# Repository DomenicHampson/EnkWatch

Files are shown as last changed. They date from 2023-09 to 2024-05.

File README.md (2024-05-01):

# EnkWatch
<h6>Note: I am still in the process of writing the firmware and mechanical design</h6>
<h4>Custom designed e-ink smartwatch with 2 weeks of battery life! The watch uses a PIC MCU with a built in RTC module and attached to an external temperature and humidity
    sensor via SPI bus to display data to the user on a e-ink screen. The time/date and off-times are set, aswell as the sensors calibrated through USB 2.0 by the user through
    python scripts. The watch is enclosed is a 3D printed shell designed using solidworks.</h4>

<h4><u>Features</u></h4>
<ul>
  <li>2 Week Battery Life: Use low power components and efficient firmware to maximize battery life</li>
  <li>Power Switching and Protection: USB power can simulatenously charge the battery and power the watch. Battery overchage protection provided by a management IC and over
      discharge protection via mosfet controlled by the PIC.</li>
  <li>USB 2.0 Communication: User can ineract with the MCU through USB to set the time/date, calibrate the altitude sensor and determine at which times to power down their watch
      (for greater battery life).</li>
</ul>

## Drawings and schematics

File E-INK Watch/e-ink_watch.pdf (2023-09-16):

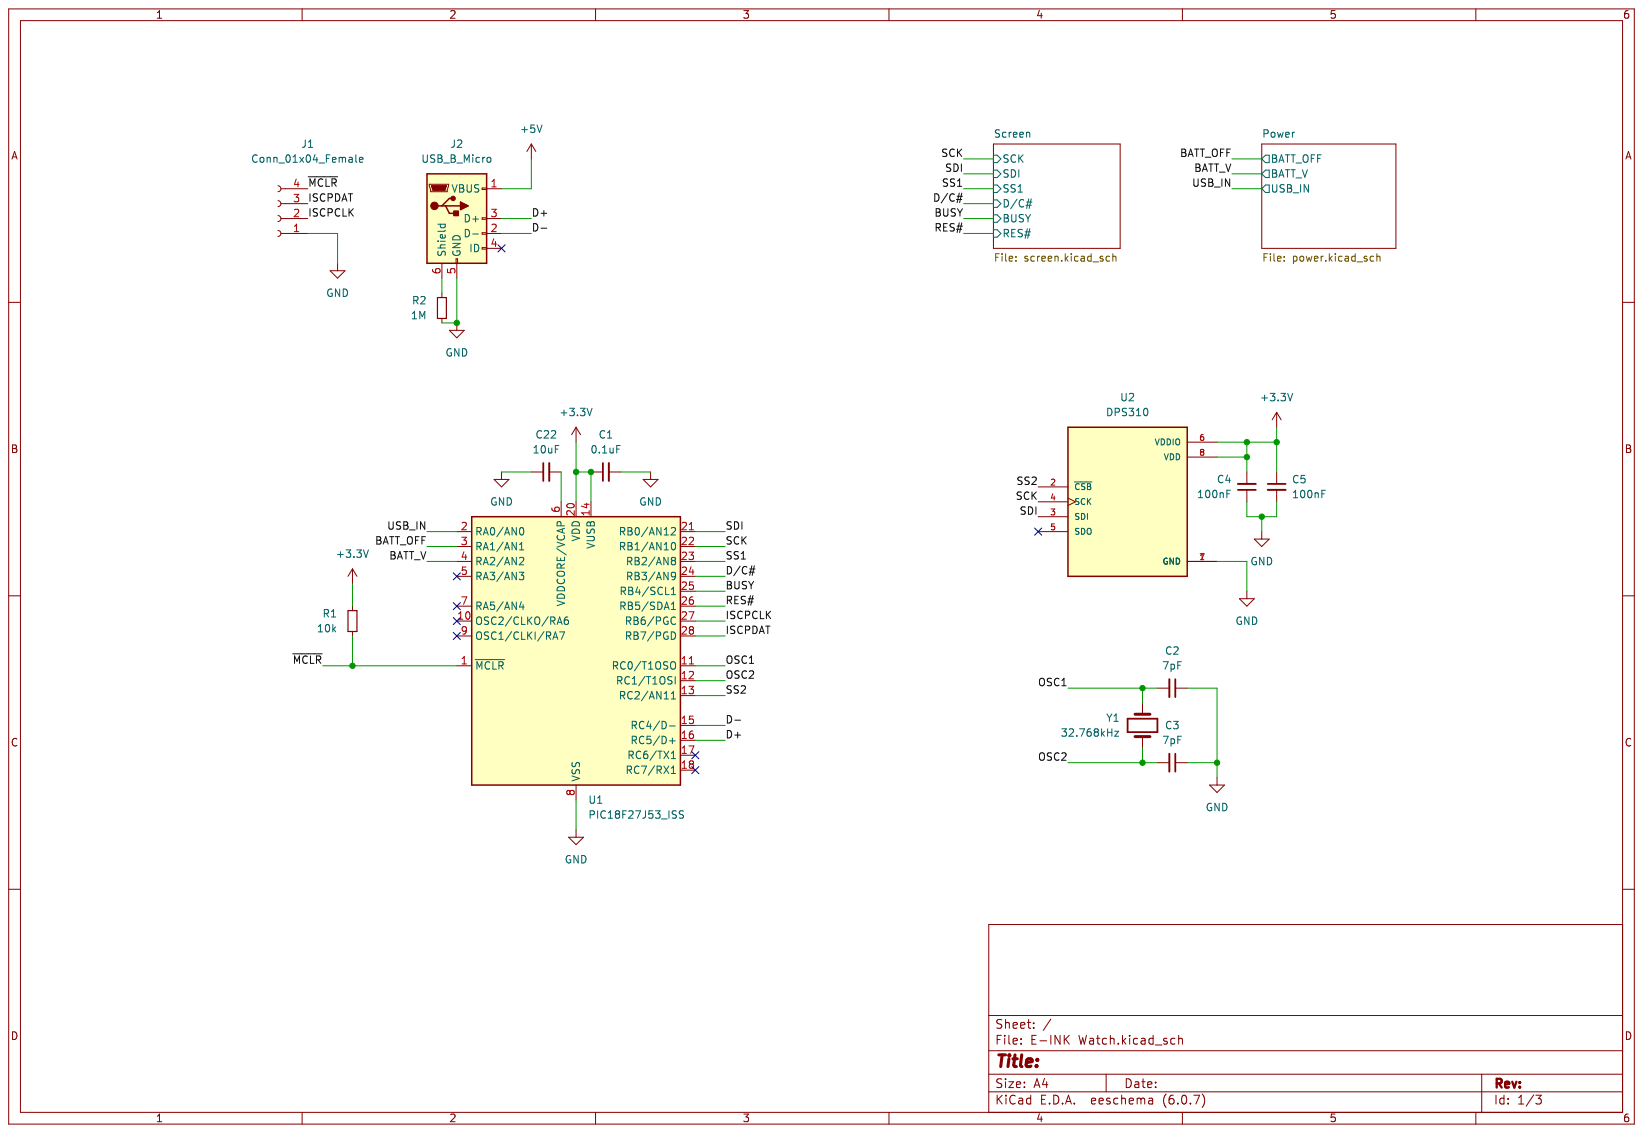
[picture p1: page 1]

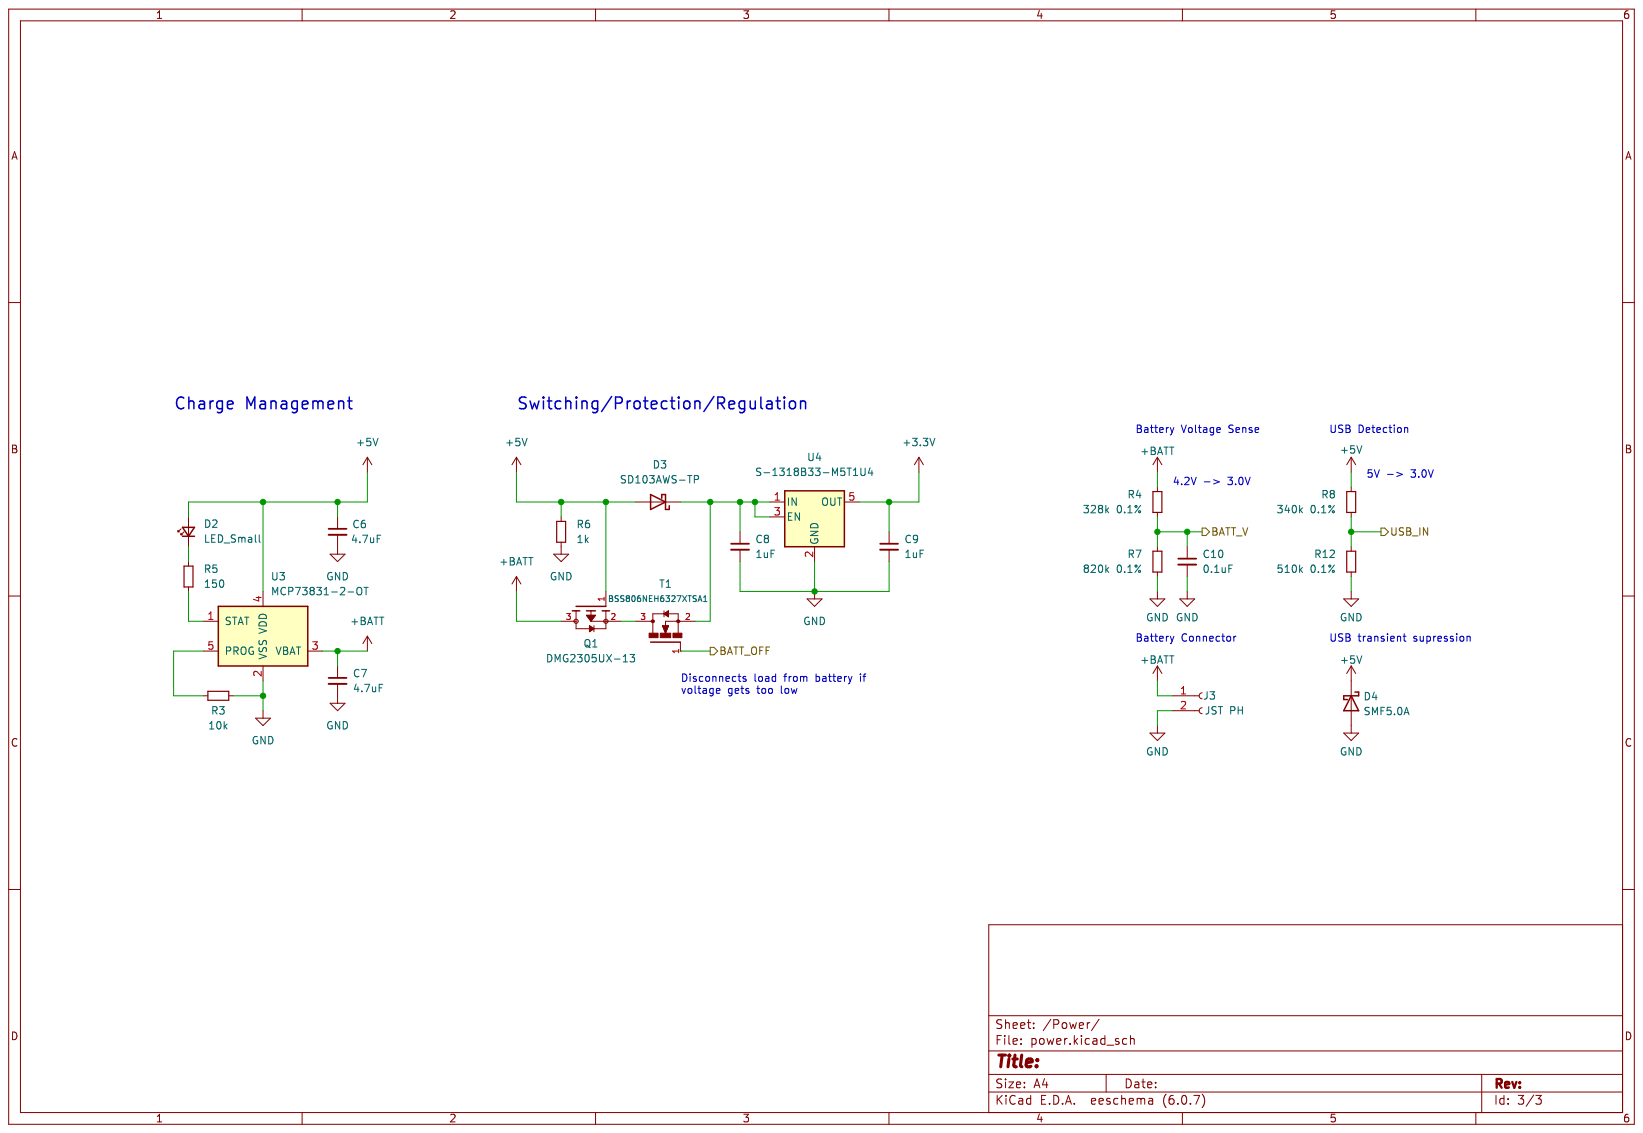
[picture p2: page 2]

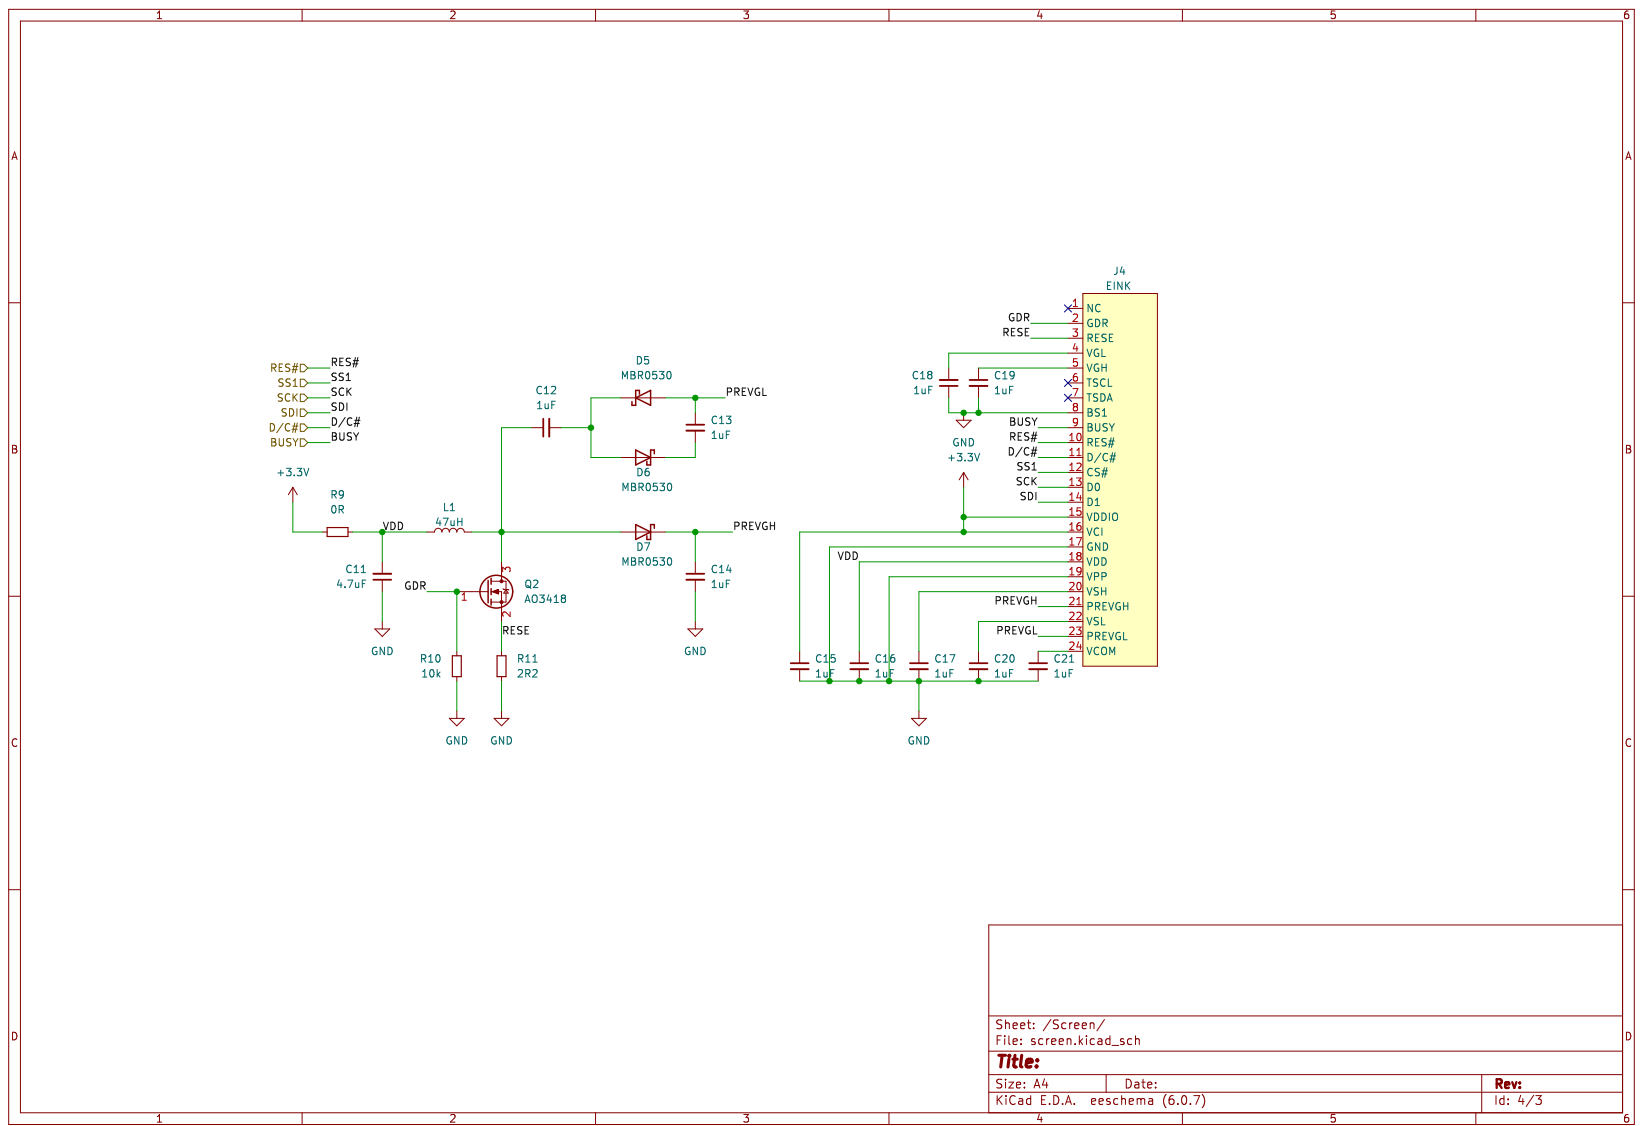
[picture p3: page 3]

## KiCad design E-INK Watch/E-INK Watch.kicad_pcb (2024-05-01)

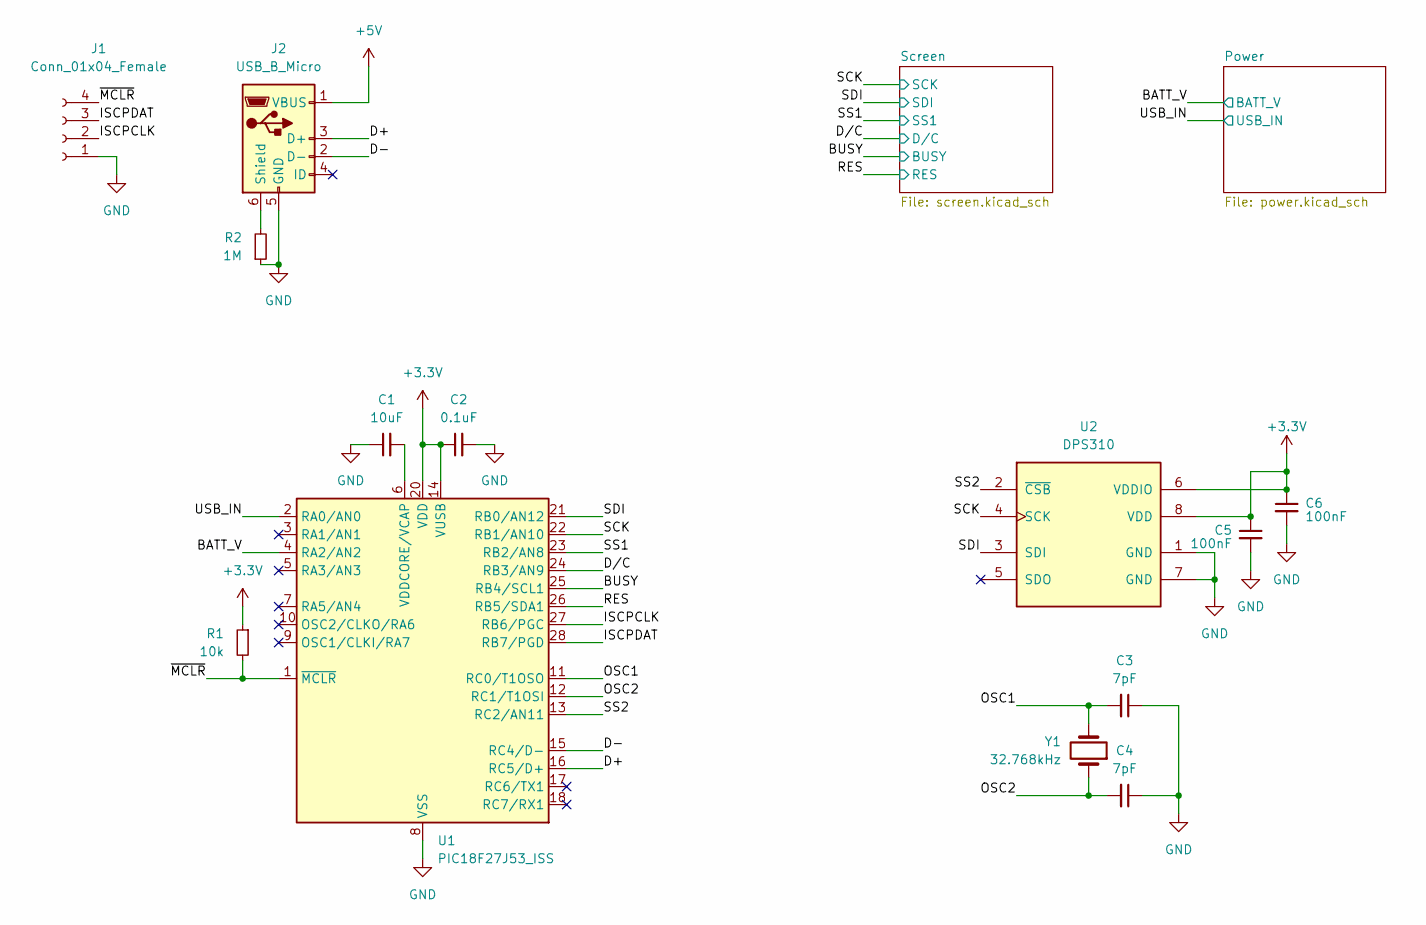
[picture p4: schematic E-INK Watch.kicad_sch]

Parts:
C1: 10uF; C_0603_1608Metric_Pad1.08x0.95mm_HandSolder
C2: 0.1uF; C_0603_1608Metric_Pad1.08x0.95mm_HandSolder
C3, C4: 7pF; C_0603_1608Metric_Pad1.08x0.95mm_HandSolder
C5, C6: 100nF; C_0603_1608Metric_Pad1.08x0.95mm_HandSolder
J1: Conn_01x04_Female; HARWIN_M20-7910442R
J2: USB_B_Micro; USB_Micro-B_Molex-105017-0001
R1: 10k; R_0603_1608Metric_Pad0.98x0.95mm_HandSolder
R2: 1M; R_0603_1608Metric_Pad0.98x0.95mm_HandSolder
U1: PIC18F27J53_ISS; SSOP-28_5.3x10.2mm_P0.65mm
U2: DPS310; XDCR_DPS310
Y1: 32.768kHz; XTAL_FC-135R_32.7680KA-AG0

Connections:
+3.3V: C2.1, C5.1, C6.1, R1.1, U1.14 (VUSB), U1.20 (VDD), U2.6 (VDDIO), U2.8 (VDD); also elsewhere on the board
+5V: J2.1 (VBUS); also elsewhere on the board
/BATT_V: U1.4 (RA2/AN2); also elsewhere on the board
/BUSY: U1.25 (RB4/SCL1); also elsewhere on the board
/D+: J2.3 (D+), U1.16 (RC5/D+)
/D-: J2.2 (D-), U1.15 (RC4/D-)
/D/C: U1.24 (RB3/AN9); also elsewhere on the board
/ISCPCLK: J1.2, U1.27 (RB6/PGC)
/ISCPDAT: J1.3, U1.28 (RB7/PGD)
/OSC1: C3.2, U1.11 (RC0/T1OSO), Y1.2
/OSC2: C4.2, U1.12 (RC1/T1OSI), Y1.1
/RES: U1.26 (RB5/SDA1); also elsewhere on the board
/SCK: U1.22 (RB1/AN10), U2.4 (SCK); also elsewhere on the board
/SDI: U1.21 (RB0/AN12), U2.3 (SDI); also elsewhere on the board
/SS1: U1.23 (RB2/AN8); also elsewhere on the board
/SS2: U1.13 (RC2/AN11), U2.2 (~CSB)
/USB_IN: U1.2 (RA0/AN0); also elsewhere on the board
/~MCLR: J1.4, R1.2, U1.1 (~MCLR)
GND: C1.1, C2.2, C3.1, C4.1, C5.2, C6.2, J1.1, J2.5 (GND), R2.1, U1.8 (VSS), U1.19 (VSS), U2.1 (GND), U2.7 (GND); also elsewhere on the board
unnamed: J2.6 (Shield), R2.2
unnamed: C1.2, U1.6 (VDDCORE/VCAP)

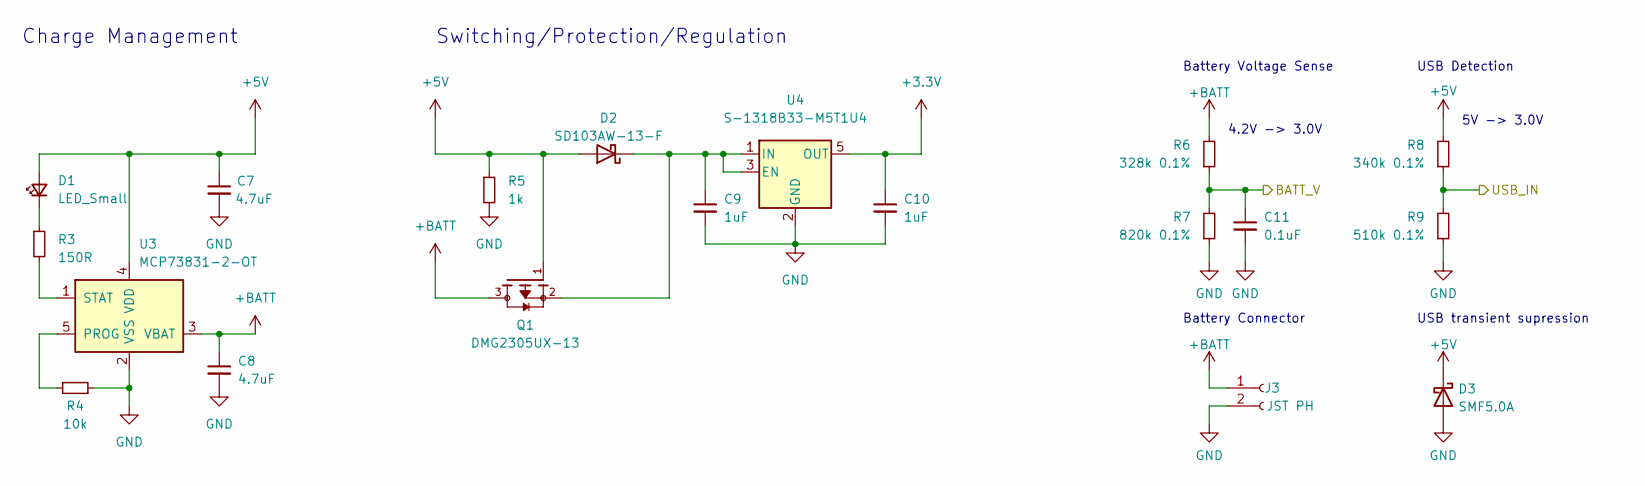
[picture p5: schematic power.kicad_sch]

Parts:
C7, C8: 4.7uF; C_0603_1608Metric_Pad1.08x0.95mm_HandSolder
C9, C10: 1uF; C_0603_1608Metric_Pad1.08x0.95mm_HandSolder
C11: 0.1uF; C_0603_1608Metric_Pad1.08x0.95mm_HandSolder
D1: LED_Small; LED_0603_1608Metric_Pad1.05x0.95mm_HandSolder
D2: SD103AW-13-F; D_SOD-123
D3: SMF5.0A; D_SOD-123F
J3: JST PH; JST_PH_S2B-PH-K_1x02_P2.00mm_Horizontal
Q1: DMG2305UX-13; SOT91P240X110-3N; PARTREV 09/2018
R3: 150R; R_0603_1608Metric_Pad0.98x0.95mm_HandSolder
R4: 10k; R_0603_1608Metric_Pad0.98x0.95mm_HandSolder
R5: 1k; R_0603_1608Metric_Pad0.98x0.95mm_HandSolder
R6: 328k 0.1%; R_0603_1608Metric_Pad0.98x0.95mm_HandSolder
R7: 820k 0.1%; R_0603_1608Metric_Pad0.98x0.95mm_HandSolder
R8: 340k 0.1%; R_0603_1608Metric_Pad0.98x0.95mm_HandSolder
R9: 510k 0.1%; R_0603_1608Metric_Pad0.98x0.95mm_HandSolder
U3: MCP73831-2-OT; SOT-23-5
U4: S-1318B33-M5T1U4; SOT-23-5

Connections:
+3.3V: C10.1, U4.5 (OUT); also elsewhere on the board
+5V: C7.1, D1.2 (A), D2.2 (A), D3.1 (K), Q1.1, R5.1, R8.2, U3.4 (VDD); also elsewhere on the board
+BATT: C8.1, J3.1, Q1.3, R6.2, U3.3 (VBAT)
/BATT_V: C11.1, R6.1, R7.2; also elsewhere on the board
/USB_IN: R8.1, R9.2; also elsewhere on the board
GND: C7.2, C8.2, C9.2, C10.2, C11.2, D3.2 (A), J3.2, R4.1, R5.2, R7.1, R9.1, U3.2 (VSS), U4.2 (GND); also elsewhere on the board
unnamed: D1.1 (K), R3.1
unnamed: C9.1, D2.1 (K), Q1.2, U4.1 (IN), U4.3 (EN)
unnamed: R4.2, U3.5 (PROG)
unnamed: R3.2, U3.1 (STAT)

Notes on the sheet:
4.2V -> 3.0V
USB transient supression
Battery Connector
USB Detection
Battery Voltage Sense
Charge Management
5V -> 3.0V
Switching/Protection/Regulation

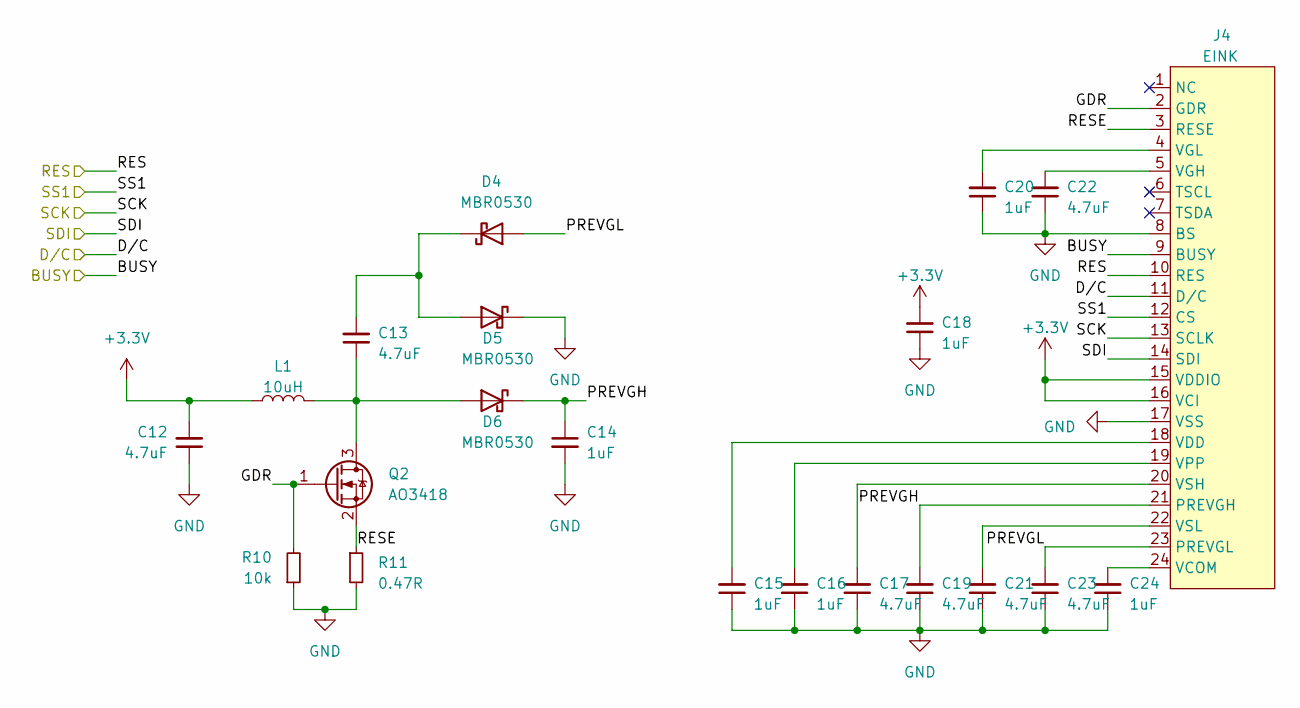
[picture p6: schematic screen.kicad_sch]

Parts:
C12, C13, C17, C19, C21, C22, C23: 4.7uF; C_0603_1608Metric_Pad1.08x0.95mm_HandSolder
C14, C15, C16, C18, C20, C24: 1uF; C_0603_1608Metric_Pad1.08x0.95mm_HandSolder
D4, D5, D6: MBR0530; D_SOD-123
J4: EINK; PANASONIC_AYF532435
L1: 10uH; L_1210_3225Metric_Pad1.42x2.65mm_HandSolder
Q2: AO3418; SOT-23
R10: 10k; R_0603_1608Metric_Pad0.98x0.95mm_HandSolder
R11: 0.47R; R_0603_1608Metric_Pad0.98x0.95mm_HandSolder

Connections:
+3.3V: C12.2, C18.2, J4.15 (VDDIO), J4.16 (VCI), L1.1; also elsewhere on the board
/BUSY: J4.9 (BUSY); also elsewhere on the board
/D/C: J4.11 (D/C); also elsewhere on the board
/RES: J4.10 (RES); also elsewhere on the board
/SCK: J4.13 (SCLK); also elsewhere on the board
/SDI: J4.14 (SDI); also elsewhere on the board
/SS1: J4.12 (CS); also elsewhere on the board
/Screen/GDR: J4.2 (GDR), Q2.1 (G), R10.2
/Screen/PREVGH: C14.1, C19.2, D6.1 (K), J4.21 (PREVGH)
/Screen/PREVGL: C23.2, D4.2 (A), J4.23 (PREVGL)
/Screen/RESE: J4.3 (RESE), Q2.2 (S), R11.1
GND: C12.1, C14.2, C15.1, C16.1, C17.1, C18.1, C19.1, C20.1, C21.1, C22.1, C23.1, C24.1, D5.1 (K), J4.8 (BS), J4.17 (VSS), R10.1, R11.2; also elsewhere on the board
unnamed: C13.2, D4.1 (K), D5.2 (A)
unnamed: C13.1, D6.2 (A), L1.2, Q2.3 (D)
unnamed: C24.2, J4.24 (VCOM)
unnamed: C15.2, J4.18 (VDD)
unnamed: C22.2, J4.5 (VGH)
unnamed: C20.2, J4.4 (VGL)
unnamed: C16.2, J4.19 (VPP)
unnamed: C17.2, J4.20 (VSH)
unnamed: C21.2, J4.22 (VSL)

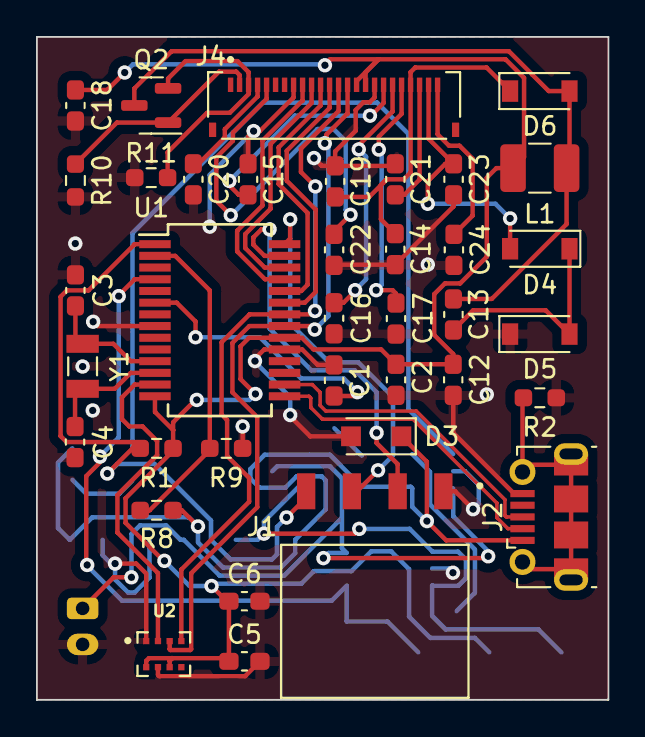
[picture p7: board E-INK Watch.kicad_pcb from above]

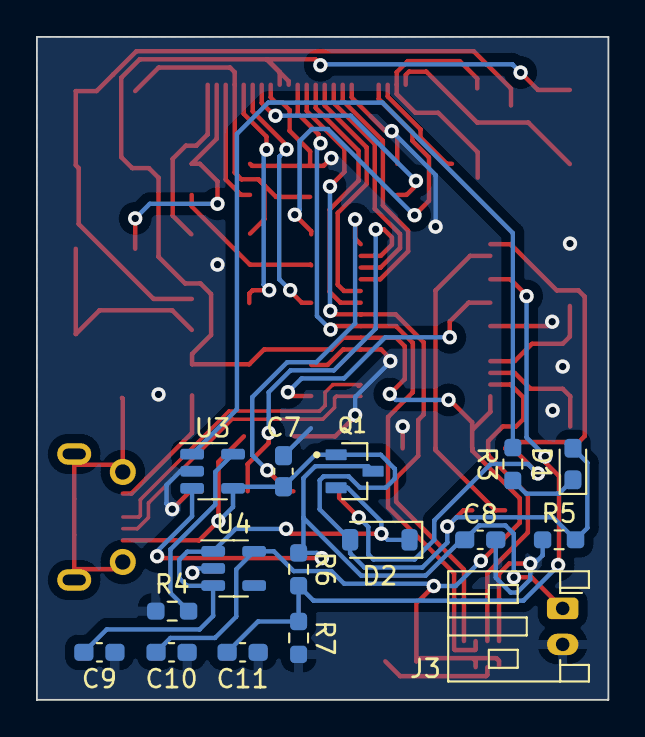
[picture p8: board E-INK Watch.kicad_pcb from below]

Board: 2 copper layers, 31.8 x 36.8 mm, 53 parts (16 on the bottom side), 39 nets.

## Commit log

2023-09-13 Added watch schematic and pcb design
    [E-INK Watch.kicad_pcb, E-INK Watch.kicad_sch, power.kicad_sch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]
2023-09-15 Cleaned up schemtic and pcb
    [E-INK Watch.kicad_pcb, E-INK Watch.kicad_sch, power.kicad_sch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]
2023-09-16 Small Schematic Modification
    [E-INK Watch.kicad_sch, power.kicad_sch, screen.kicad_sch]
2024-05-01 Completed PCB and gerber files
    [E-INK Watch-B_Cu.gbr, E-INK Watch-B_Mask.gbr, E-INK Watch-B_Silkscreen.gbr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]
2024-05-01 removed unnecesary gerber files
    [E-INK Watch-B_Cu.gbr, E-INK Watch-B_Mask.gbr, E-INK Watch-B_Silkscreen.gbr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]
